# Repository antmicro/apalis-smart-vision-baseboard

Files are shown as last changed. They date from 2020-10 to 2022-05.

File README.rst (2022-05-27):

=============================
Apalis Smart Vision Baseboard
=============================

Copyright (c) 2016-2021 `Antmicro <https://www.antmicro.com>`_





Overview
========

This repository contains open hardware design files for Antmicro’s Apalis Smart Vision Baseboard - a custom baseboard for the Toradex `Apalis family <https://www.toradex.com/computer-on-modules/apalis-arm-family>`_ of SoMs (Systems on Module). The board has a unified FFC connector exposing the MIPI CSI-2 interfaces of the Apalis modules. The FFC connector is electrically compatible with a range of image acquisition platforms developed by Antmicro.

Repository structure
--------------------

The main repository directory contains the Altium PCB project file, the Outjob file, LICENSE and README.
The remaining files are stored in the following directories:

* ``PCB`` -  contains all Altium design files
* ``Libraries`` - contains the component libraries
* ``Documentation`` - contains selected files for device fabrication (schematics in PDF, BoM) generated from the Altium project files
* ``Images`` - contains graphics for this README
* ``3DModel`` - contains files defining the mechanical model of the assembled board

Key features
============

* Toradex Apalis SoM edge connector
* FFC interface exposing up to 2 x 4-lane MIPI CSI-2, depending on the Apalis SoM used
* mSATA connector
* miniPCIe connector
* USB 3.0 host interface
* HDMI output interface
* 2 x Micro USB (debug and OTG)
* Gigabit Ethernet RJ45 connector
* Micro SIM slot
* RTC battery backup
* 9-24V DC power supply voltage

The PCB project files were prepared in Altium Designer 14.1.

Board layout & dimensions
=========================

The picture below presents a general layout of the PCB with marked I/O interfaces.

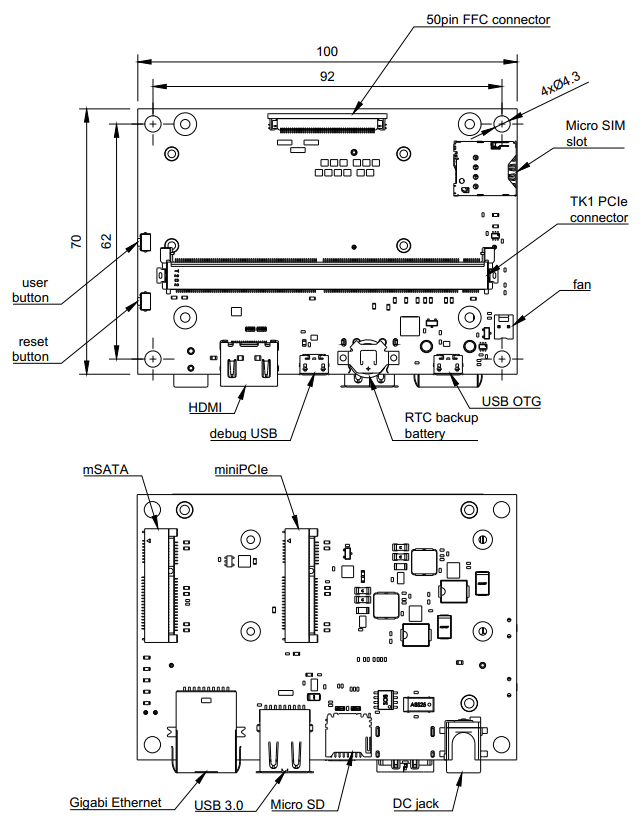
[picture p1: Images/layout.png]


Getting started
===============

The board can be produced and assembled using the provided design files.
Refer to the mechanical layers for more information regarding the PCB stackup recommended for fabrication.
The board accepts power supply voltage in the 6-24VDC range.
It is recommended to use a 12V 2A DC supply to power the board.
The module will start automatically right after applying a power supply.

Debug UART connection
---------------------

Most of the debug messages are provided through the serial console.
The board is equipped with an FTDI chip providing the UART interface to the host PC.
Refer to the schematic sheets for more details.
The default debug UART channel is accessible through ``/dev/ttyUSB0`` (assuming that there are no other FTDI units connected to your PC).
The default baudrate for the serial debug connection is 115200 baud with an 8-bit transmission, 1 stop bit and with no flow control.

License
=======

`Apache-2.0 <LICENSE>`_

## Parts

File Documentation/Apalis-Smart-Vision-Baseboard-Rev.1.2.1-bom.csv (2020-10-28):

Designator | Quantity | Value | Footprint | Manufacturer | MPN
Y1 | 1 | 32.768 kHz | ABS25 | ABRACON | ABS25-32.768KHZ-6-T
J5 | 1 | 114-00841-68 | 114-00841-68 | AMPHENOL COMMERCIAL PRODUCTS | 114-00841-68
IC6, IC7 | 2 | AD8211YRJ | SOT23-5 | ANALOG DEVICES | AD8211YRJ
C13, C14, C36, C56, C59 | 5 | 10n | 0402 | AVX | 04025G103ZAT2A
R24 | 1 | 0R | 0603 | BOURNS | CR0603-J/-000ELF
RST, USR | 2 | TL3340AF160QG | TL3340AF160QG | E-SWITCH | TL3340AF160QG
IC5 | 1 | FT232RQ | QFN-32 | FTDI | FT232RQ-REEL
M1 | 1 | MM70-314-310B1 | Apalis-H | JAE Electronics | MM70-314-310B1
C11, C12 | 2 | 22u | KEMET_C | KEMET | T491C226K025AT
BAT1 | 1 | 3030 | KEYSTONE_CR1025 | Keystone | 3030
D18, D21 | 2 | KPT-1608EC | LED0603 | KINGBRIGHT | KPT-1608EC
D19 | 1 | KPJA-2107CKCK | KPJA-2107 | KINGBRIGHT | KPJA-2107CKCK
D20 | 1 | KPJA-2107SYCK | KPJA-2107 | KINGBRIGHT | KPJA-2107SYCK
D4, D10, D11, D15, D16, D17 | 6 | KPT-1608SGC | LED0603 | KINGBRIGHT | KPT-1608SGC
IC2, IC3 | 2 | LT3976EMSE#PBF | LT3976EMSE | LINEAR TECHNOLOGY | LT3976EMSE#PBF
IC8 | 1 | TC1047AVNBTR | SOT-23 | MICROCHIP | TC1047AVNBTR
IC9 | 1 | MCP79410 | SOIC-8 | MICROCHIP | MCP79410-I/SN
J10, J12 | 2 | Molex 47346-0001 | CON-Molex-047346-0001 | Molex | 473460001
J11 | 1 | MX-22-23-2021 | molex_2223-2021 | Molex | 022232021 A-6373-02A222
J7 | 1 | 47151-1001 | Molex_HDMI_471511001 | MOLEX | 47151-1001
C15, C16 | 2 | 470p | 0402 | MULTICOMP | MC0402B471J500CT
C18, C19, C21, C22, C23, C24, C25, C26, C27, C35, C47, C48, C50 | 13 | 4u7 | 0603 | MULTICOMP | MC0603X475K6R3CT
C3, C4 | 2 | 10p | 0402 | MULTICOMP | MC0402N100D500CT
C32, C51 | 2 | 1u | 0402 | MULTICOMP | MC0402F105Z6R3CT
R11, R13, R26, R27, R31, R32, R41, R44, R45 | 9 | 330R | 0402 | MULTICOMP | MCMR04X3300FTL
R5 | 1 | 576k | 0402 | MULTICOMP | MCMR04X5763FTL
R6 | 1 | 130k | 0402 | MULTICOMP | MCMR04X1303FTL
R8 | 1 | 54k9 | 0402 | MULTICOMP | MCMR04X5492FTL
R9, R10, R16, R17, R18, R20, R21, R22, R28, R38, R39, R40, R46 | 13 | 10k | 0402 | MULTICOMP | MCMR04X1002FTL
C1 | 1 | 4u7 | 0402 | MURATA | GRM155R60G475ME
C7, C8, C9, C10 | 4 | 47u | 1206 | MURATA | GRM31CC80J476KE18L
L1 | 1 | LQH3NPN2R2NM0L | LQH3NPN2R2NM | MURATA | LQH3NPN2R2NM0L
L4, L5, L6, L9 | 4 | BLM18SG121TN1D | 0603 | MURATA | BLM18SG121TN1D
IC4 | 1 | IP4791CZ12 | IP4791CZ12 | NXP | IP4791CZ12
Q1, Q3 | 2 | PMGD780SN | SOT-363 | NXP | PMGD780SN,115
D1, D2 | 2 | MBRS540T3G | SMC-403-03 | ON SEMICONDUCTOR | MBRS540T3G
D3 | 1 | BAV70LT3G | SOT-23 | ON SEMICONDUCTOR | BAV70LT3G
IC11 | 1 | NCP380HSNAJAAT1G | TSOP-6 | ON Semiconductor | NCP380HSNAJAAT1G
R25 | 1 | 0R | 0402 | Panasonic | ERJ2GE0R00X
R29, R30 | 2 | 0R05 | 1206 | PANASONIC | ERJL08KF50MV
R33, R34, R42, R43 | 4 | 4k7 | 0402 | Panasonic | ERJ2GEJ472X
R53 | 1 | 13k | 0402 | Panasonic | ERJ2GEJ133X
IC12, IC13, IC14, IC15, IC16, IC17, IC18, IC19, IC20, IC21, IC22, IC23 | 12 | EClamp8052P | SGP1917N5 | SEMTECH | ECLAMP8052P.TCT
C17, C33, C34, C37, C41, C49, C52, C60 | 8 | 100n | 0402 | TDK | C1005X5R0J104K050BA
C20 | 1 | 10u | 0402 | TDK | C1005X5R0J106M050BC
C5, C6 | 2 | 470n | 0402 | TDK | MC0402X474K6R3CT
J2, J4 | 2 | 1759503-1 | 1759503-1 | TE CONNECTIVITY | 1759503-1
D5, D7, D9, D22 | 4 | TPD4E05U06 | TPD4E05U06_PASS | Texas Instruments | TPD4E05U06DQAR
D6, D12, D13, D14 | 4 | TPD6E05U06 | TPD6E05U06_PASS | Texas Instruments | TPD6E05U06RVZR
D8, D23 | 2 | TPD2E2U06DRLR | TPD2E2U06DRLR | Texas Instruments | TPD2E2U06DRLR
IC1 | 1 | LM3671MF-1.5 | SOT23-5N | TEXAS INSTRUMENTS | LM3671MF-1.5/NOPB
IC10 | 1 | ADS1015IDGST | MSOP10 | TEXAS INSTRUMENTS | ADS1015IDGST
C42 | 1 | 100u | KEMET_A | VISHAY | 298D107X06R3A2T
L2, L3 | 2 | IHLP2525CZER2R2M01 | IHLP-2525CZ-01 | VISHAY | IHLP2525CZER3R3M01
Q2 | 1 | SI2323DS | SOT-23 | Vishay | SI2323DS-T1-E3
R1, R2 | 2 | 1M | 0402 | VISHAY | CRCW04021M00FKED
R14, R15 | 2 | 22R | 0402 | VISHAY | CRCW040222R0FKED
R37 | 1 | 470R | 0402 | VISHAY | CRCW0402470RFKED.
R7 | 1 | 316k | 0402 | VISHAY | CRCW0402316KFKED
C2, C28, C29, C30, C31, C38, C39, C40, C43, C44, C45, C46, C55, C57, C58 | 15 | 10u | 0603 | Walsin | 0603X106M6R3CT
C53, C54 | 2 | 6p | 0402 | WALSIN | 0402N6R0D500CT
J1 | 1 | 694106106102 | 694106106102 | WURTH ELEKTRONIK | 694106106102
J3 | 1 | 693021010811 | 693021010811 | WURTH ELEKTRONIK | 693021010811
J6 | 1 | 68715014522 | 68715014522 | WURTH ELEKTRONIK | 68715014522
J8 | 1 | 692122030100 | 692122030100 | WURTH ELEKTRONIK | 692122030100
J9 | 1 | 7498111001A | 7498111001A | WURTH ELEKTRONIK | 7498111001A
SP1, SP2 | 2 | 9774030360 | M3-3mm | WURTH ELEKTRONIK | 9774030360
SP3, SP4, SP5, SP6 | 4 | 9774050151 | M2.5-5mm | WURTH ELEKTRONIK | 9774050151
SP7, SP8 | 2 | 9774080360 | M3-8mm | WURTH ELEKTRONIK | 9774080360
R3, R4 | 2 | 2R | 0402 | YAGEO | MC00625W040212R0

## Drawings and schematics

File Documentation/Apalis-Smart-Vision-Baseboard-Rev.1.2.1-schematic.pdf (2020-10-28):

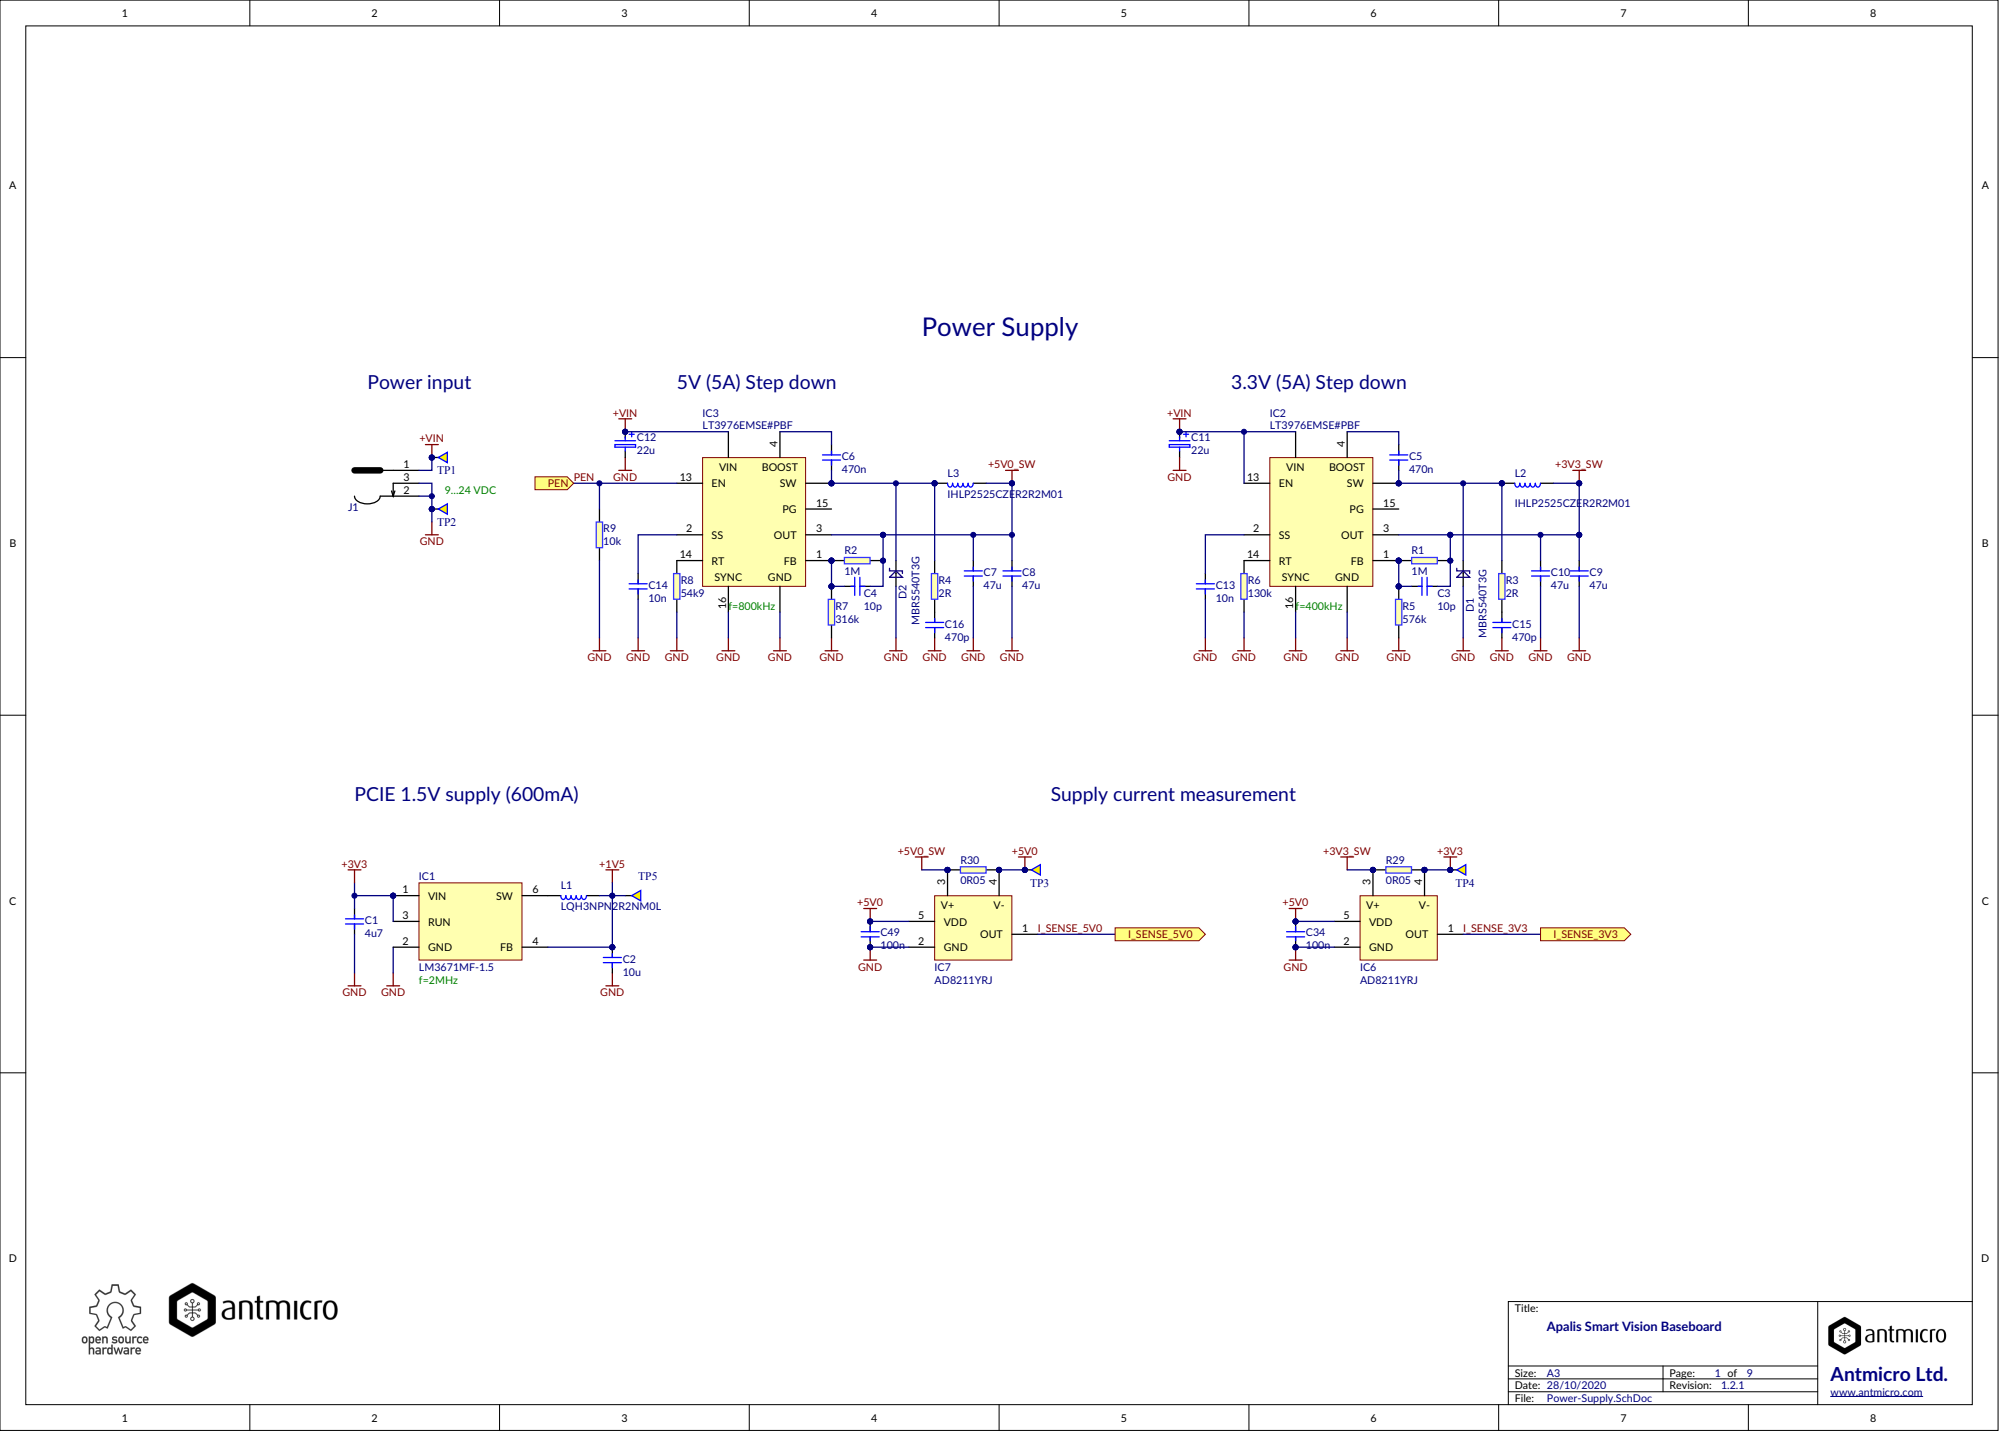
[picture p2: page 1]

Title: Apalis Smart Vision Baseboard

Size: A3 | Page: 1 of 9 | Antmicro Ltd. www.antmicro.com
Date: 28/10/2020 | Revision: 1.2.1

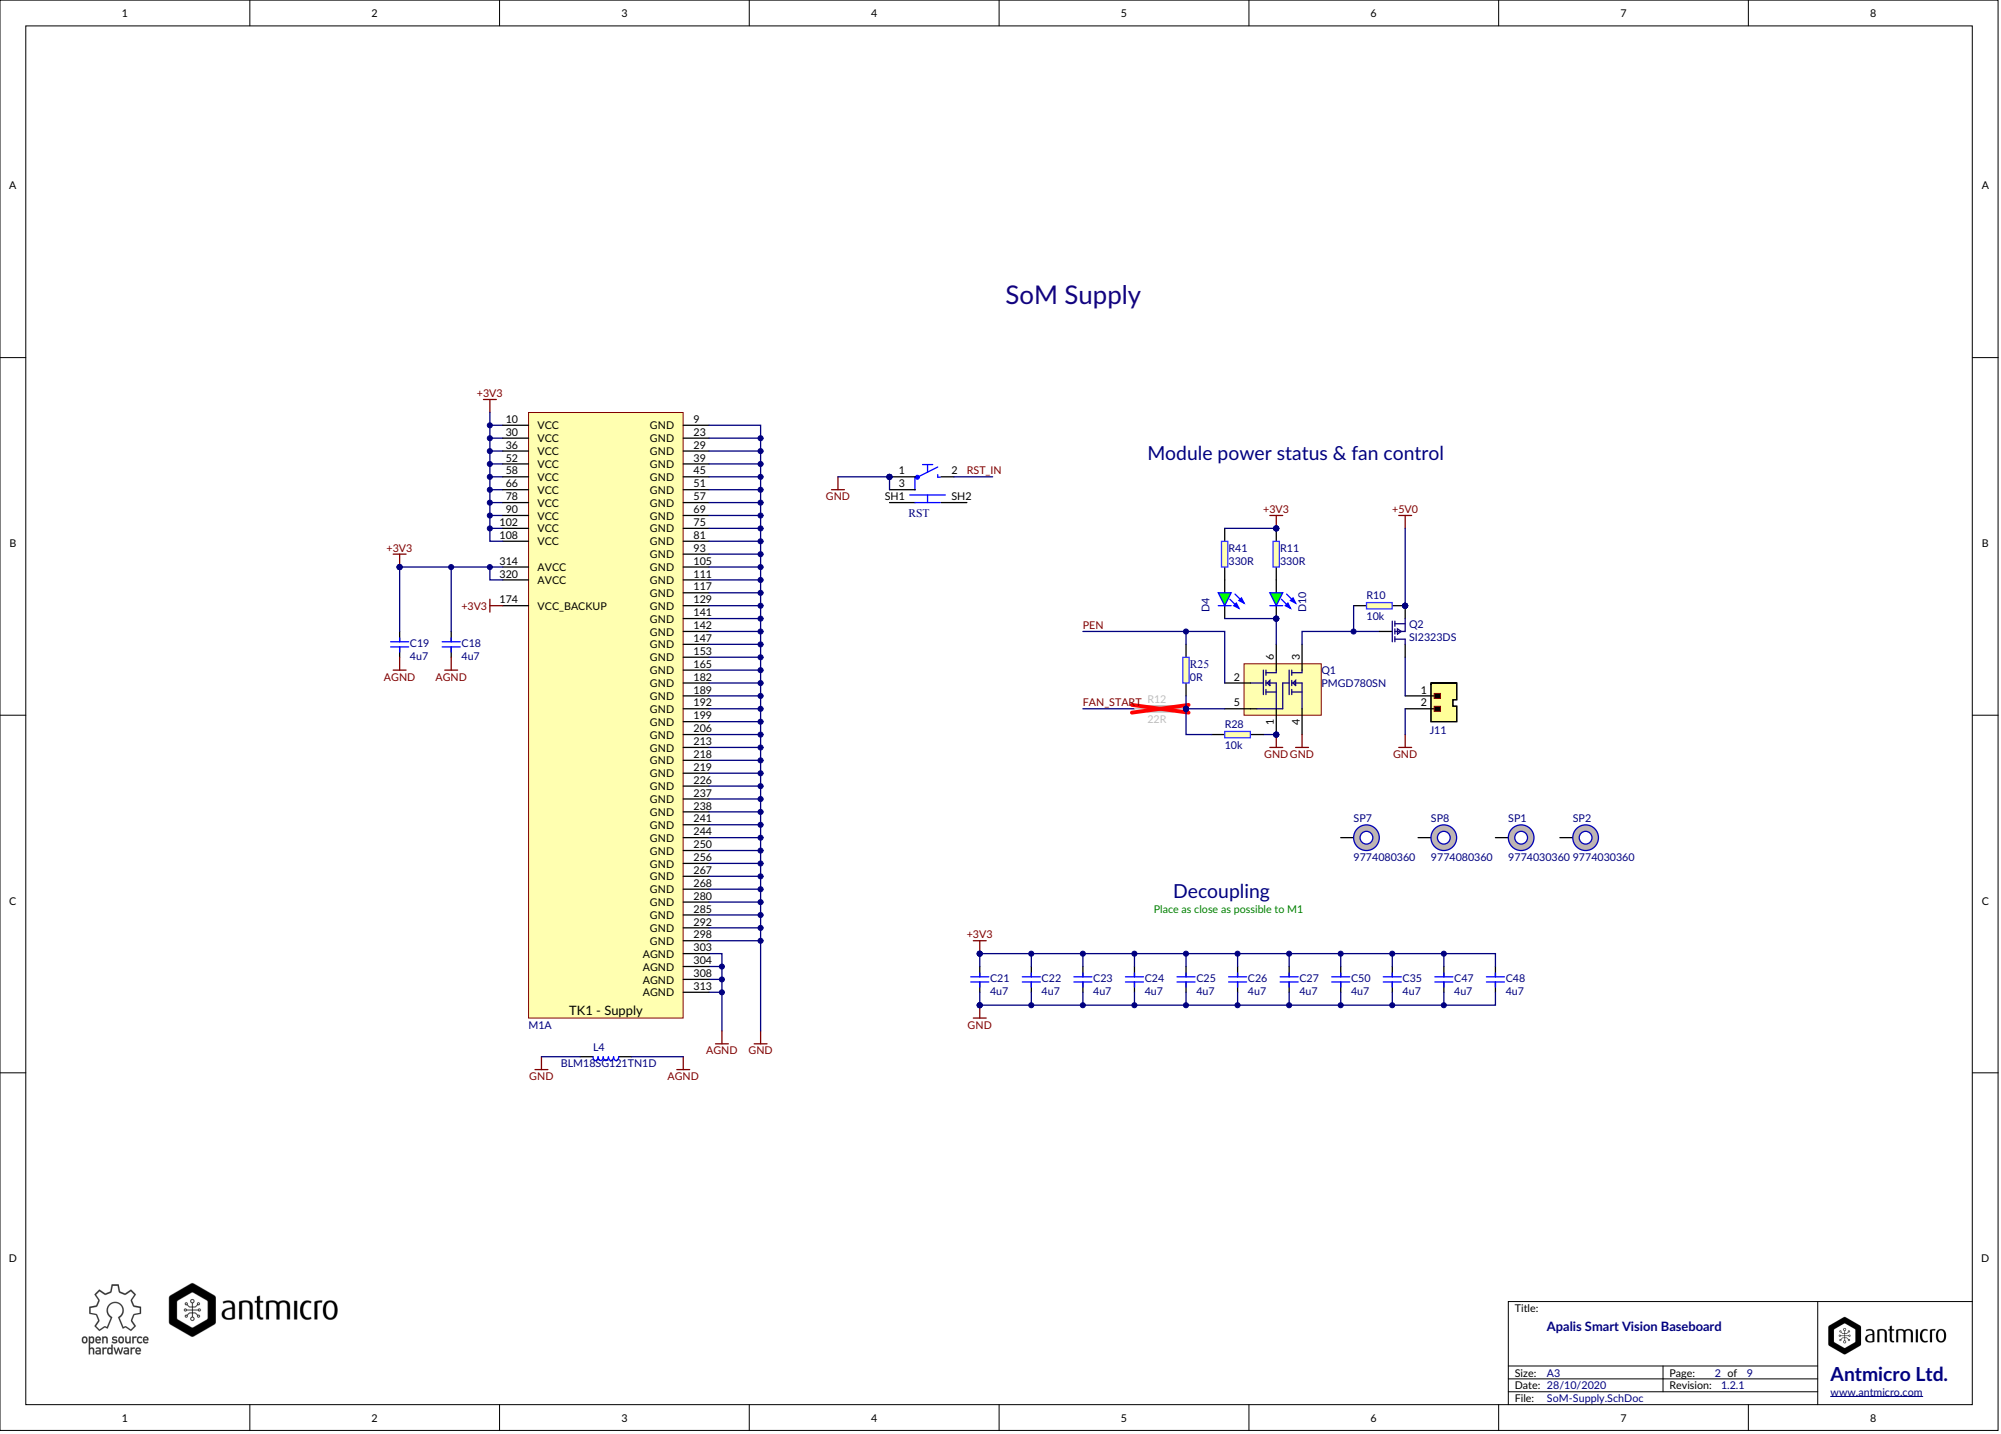
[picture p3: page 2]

VCC 30
VCC 36
VCC 52
VCC 58

Module power status & fan control

VCC 78

VCC 102

Place as close as possible to M1

Title:

A3 | Page: 2 of 9

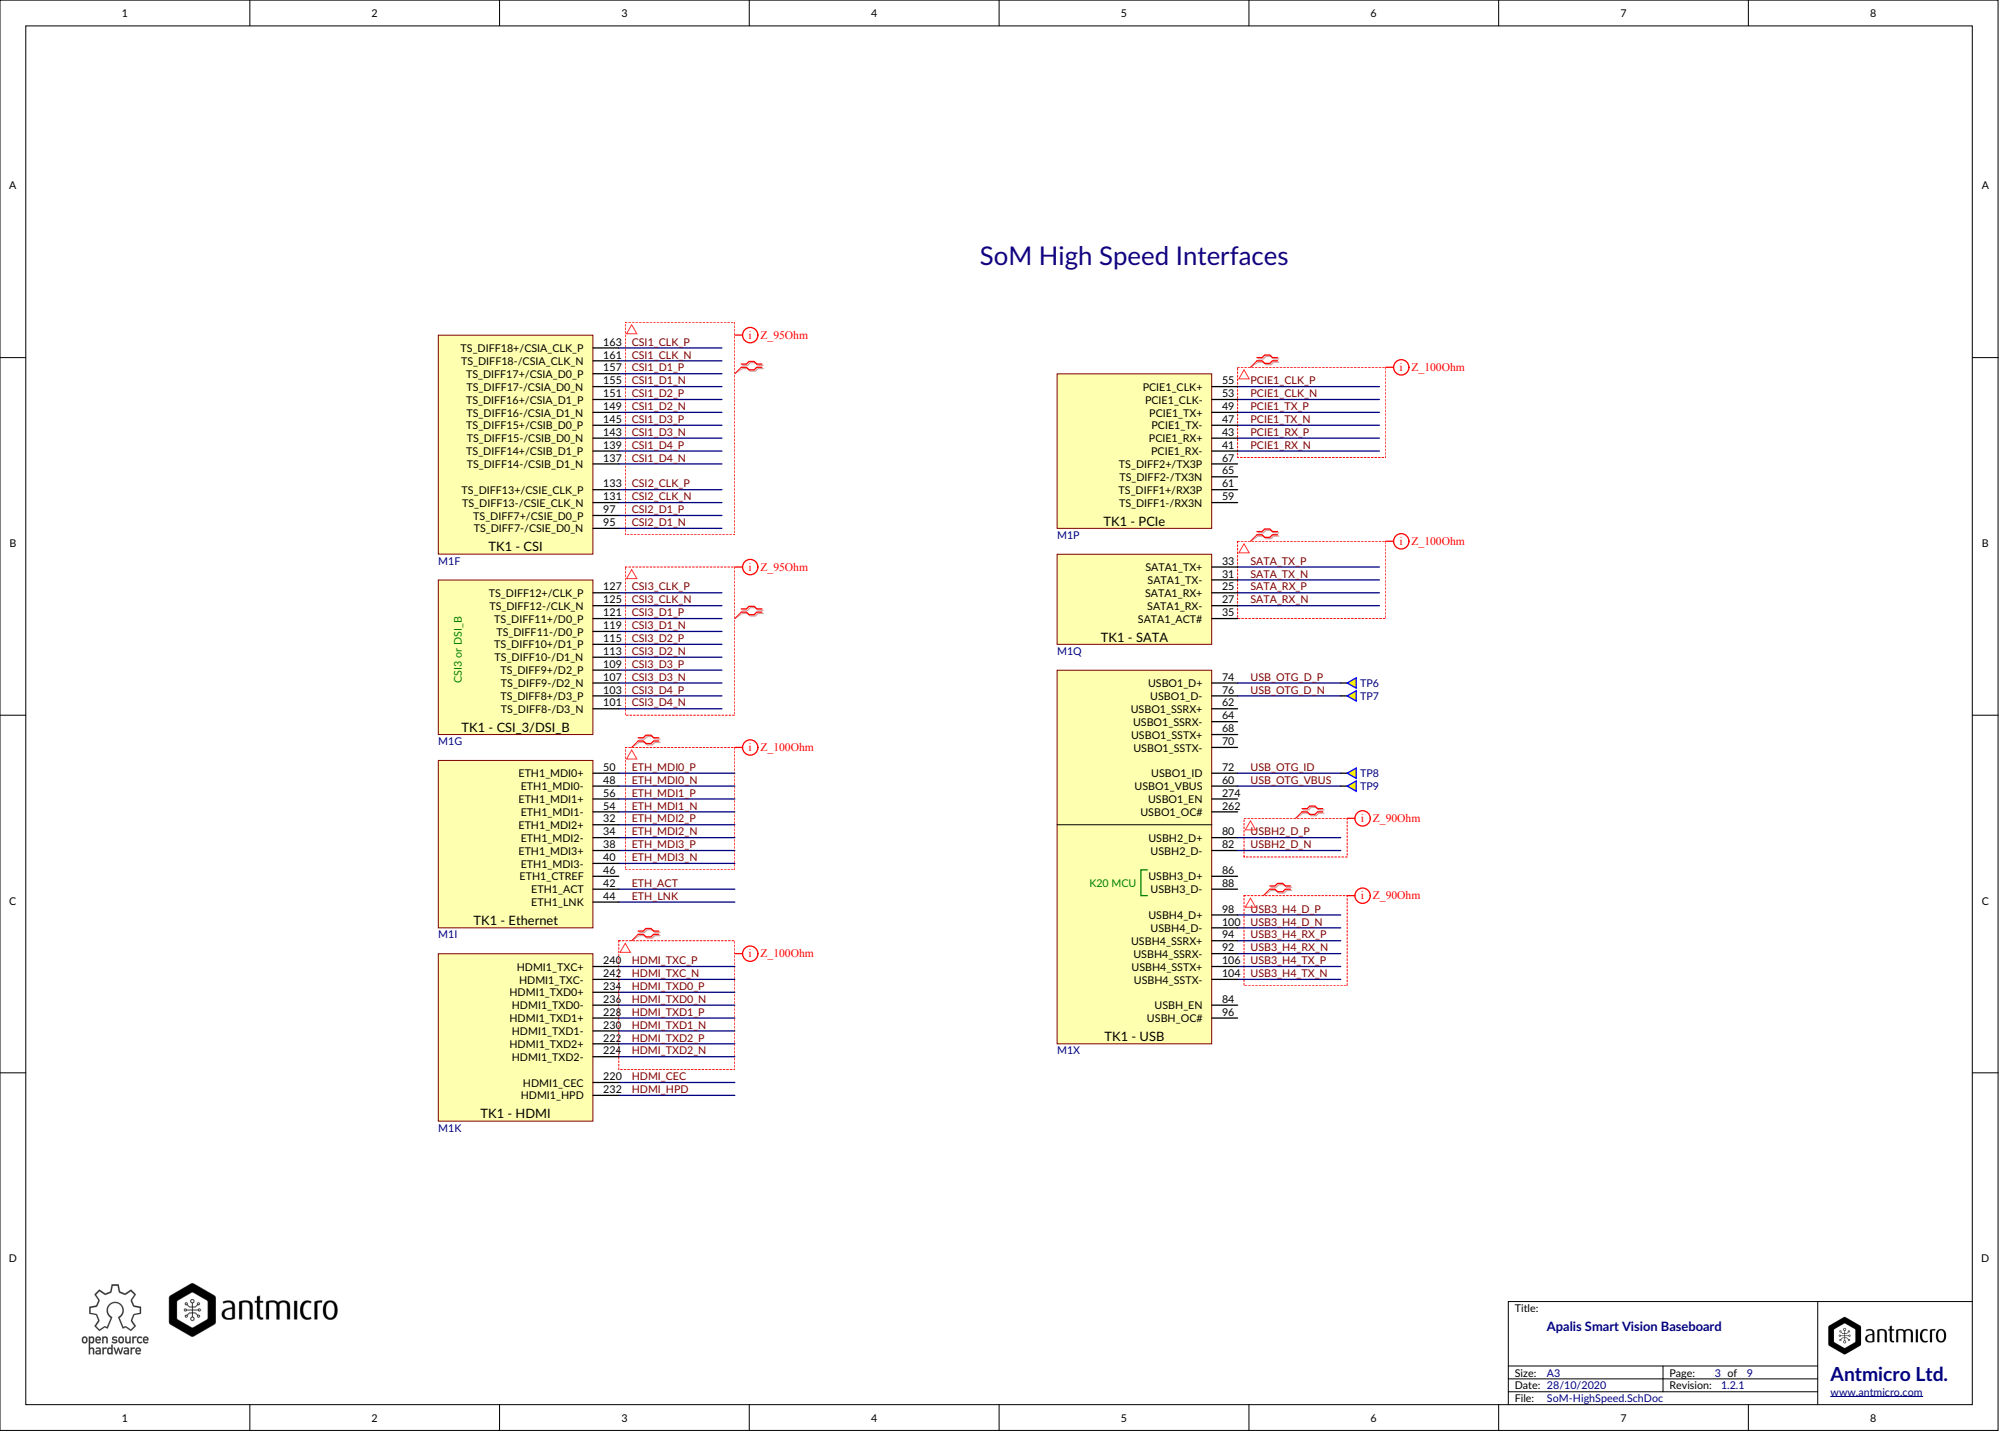
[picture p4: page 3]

SoM High Speed Interfaces

Title:

A3 | Page: 3 of

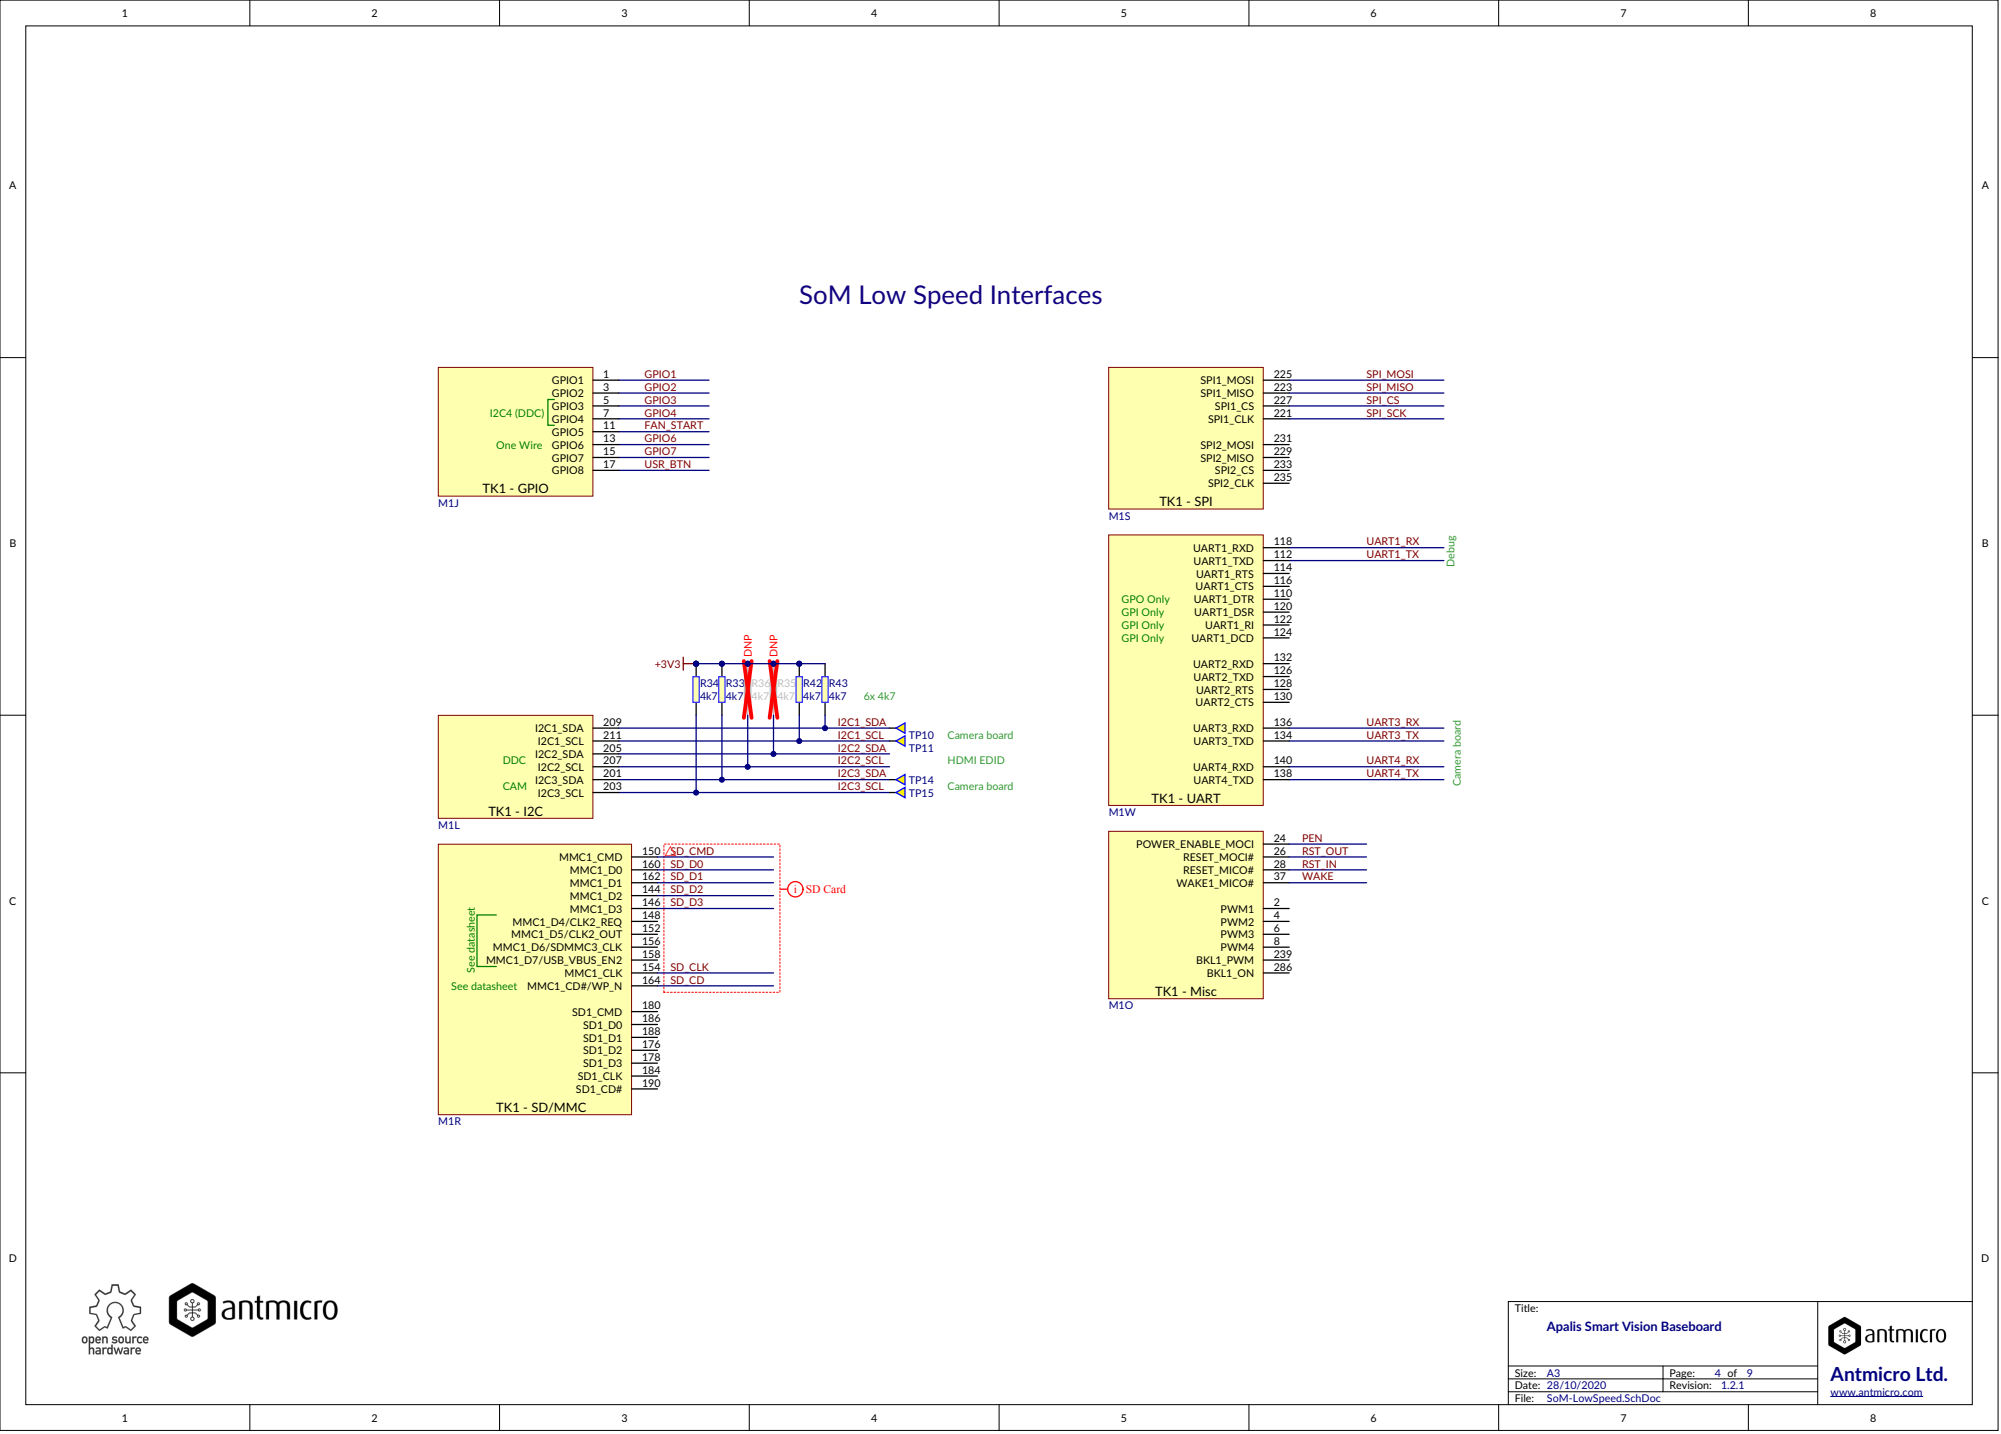
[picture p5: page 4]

SoM Low Speed Interfaces

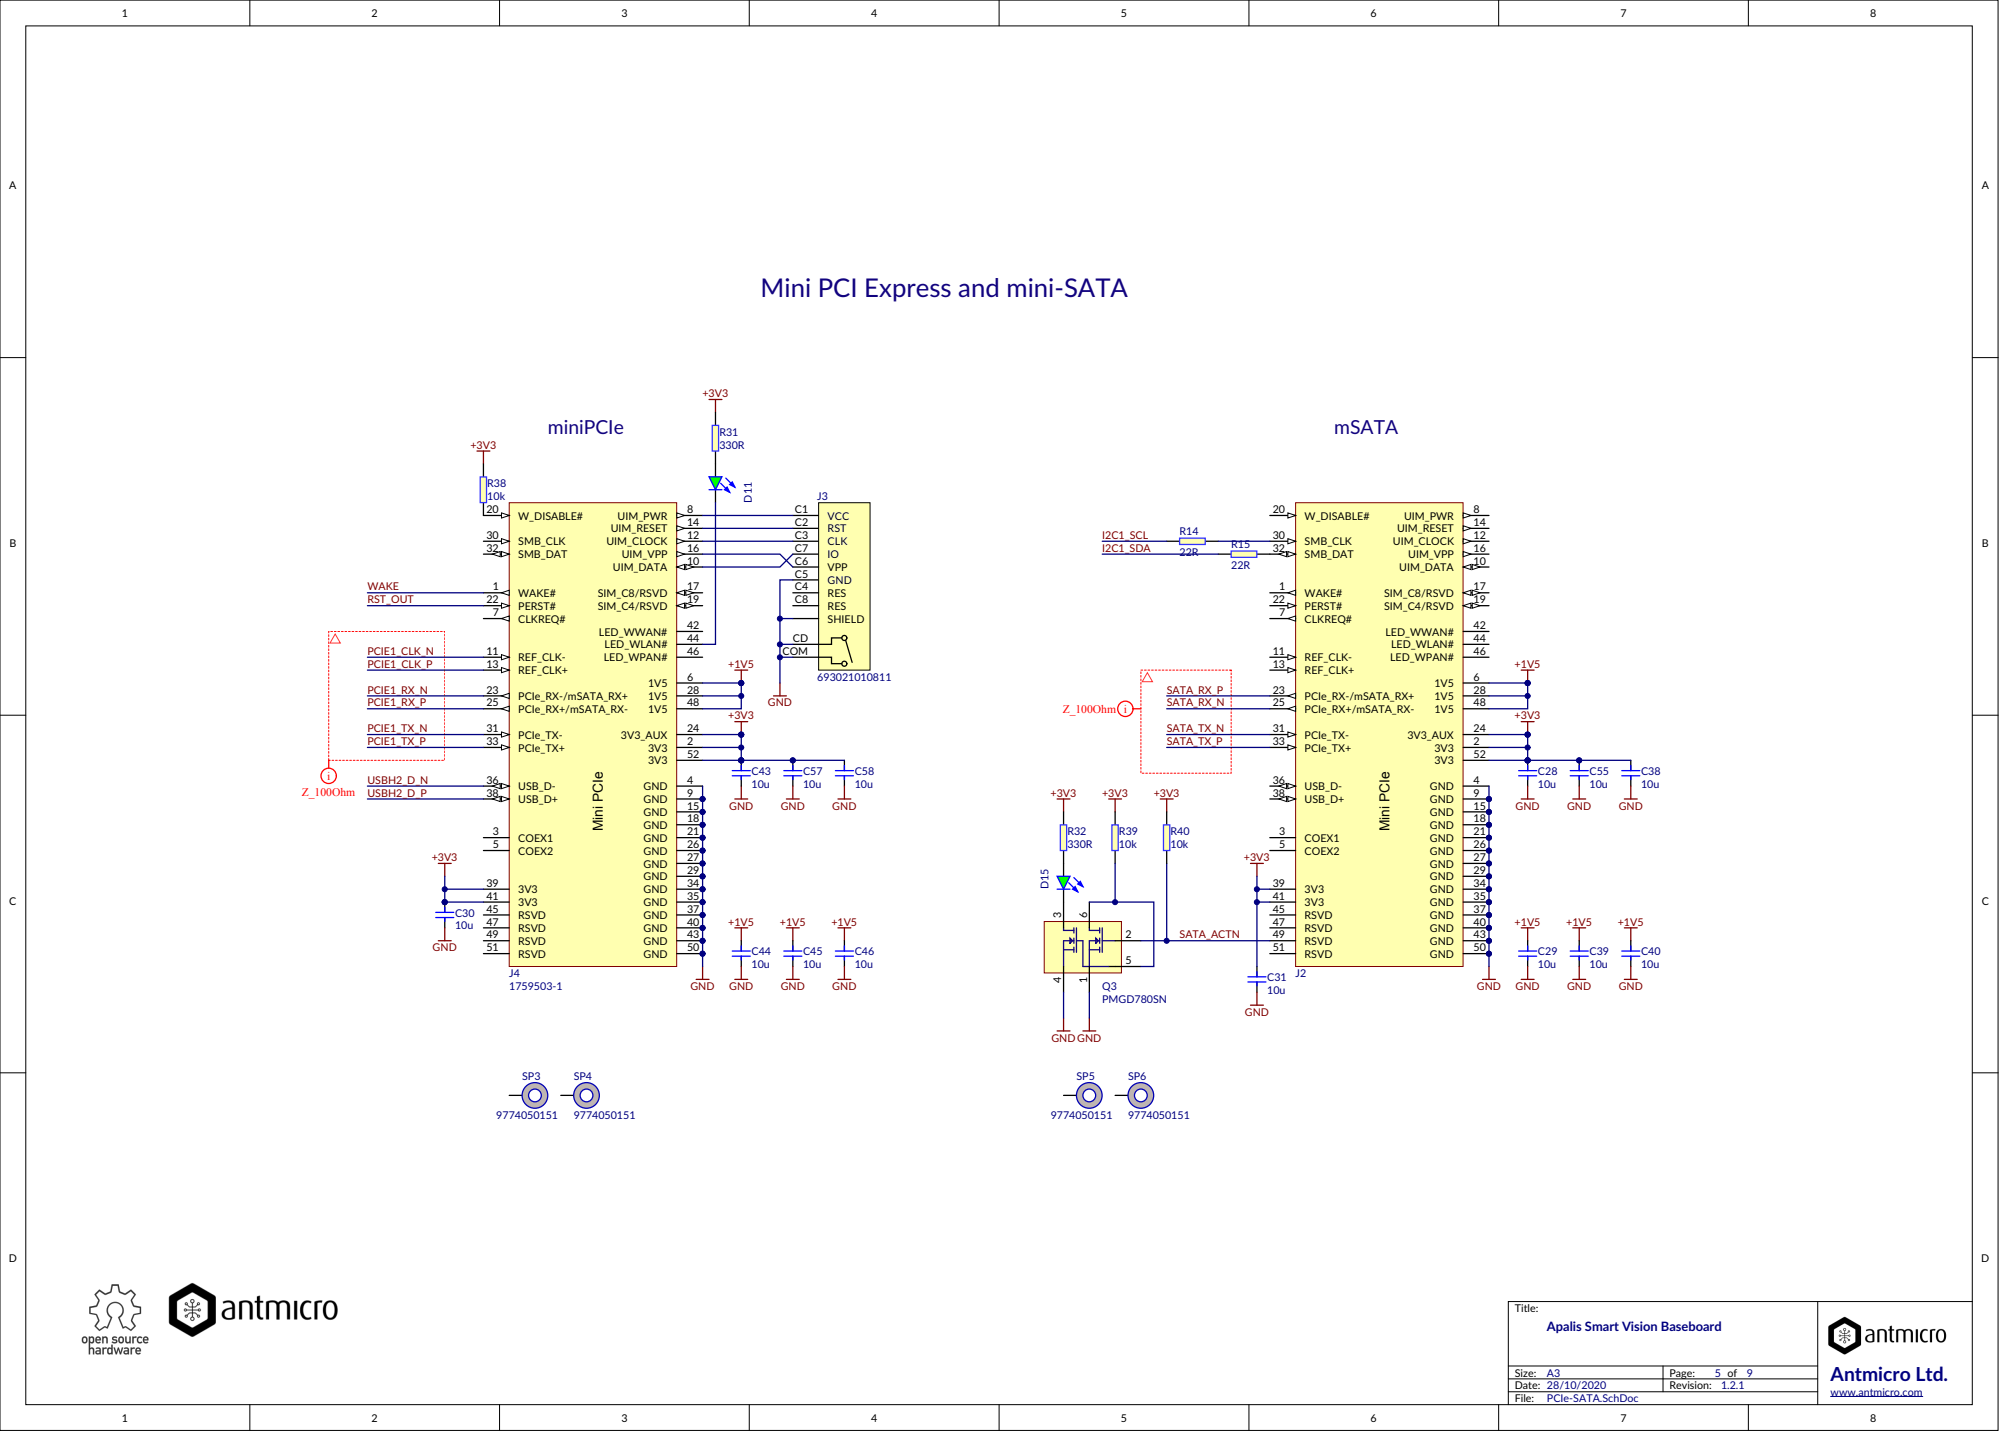
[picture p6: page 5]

Mini PCI Express and mini-SATA

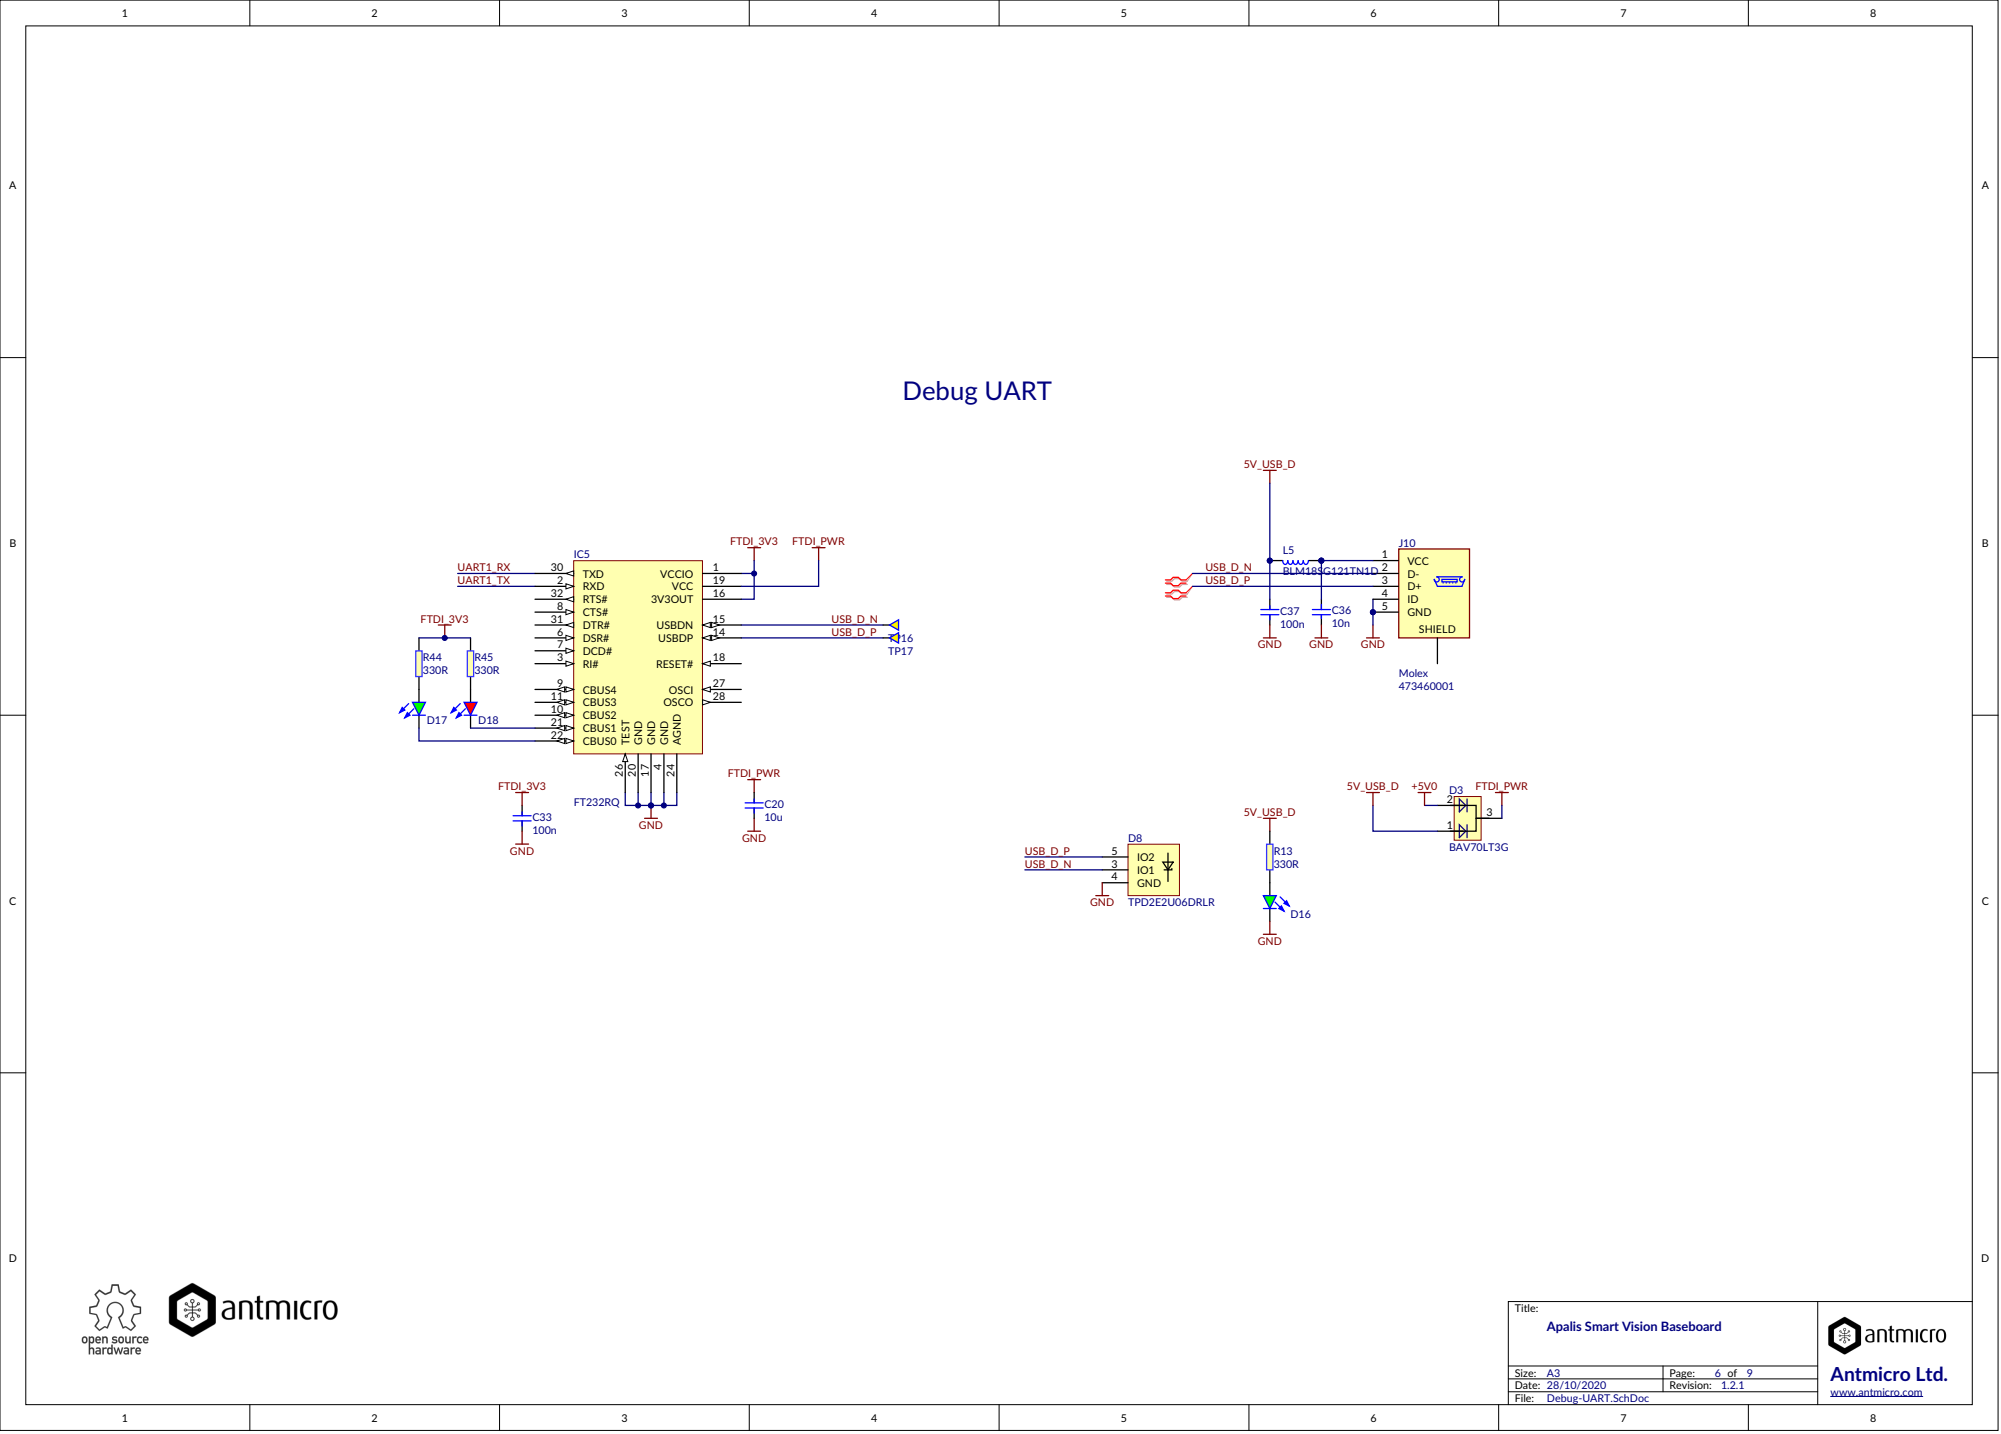
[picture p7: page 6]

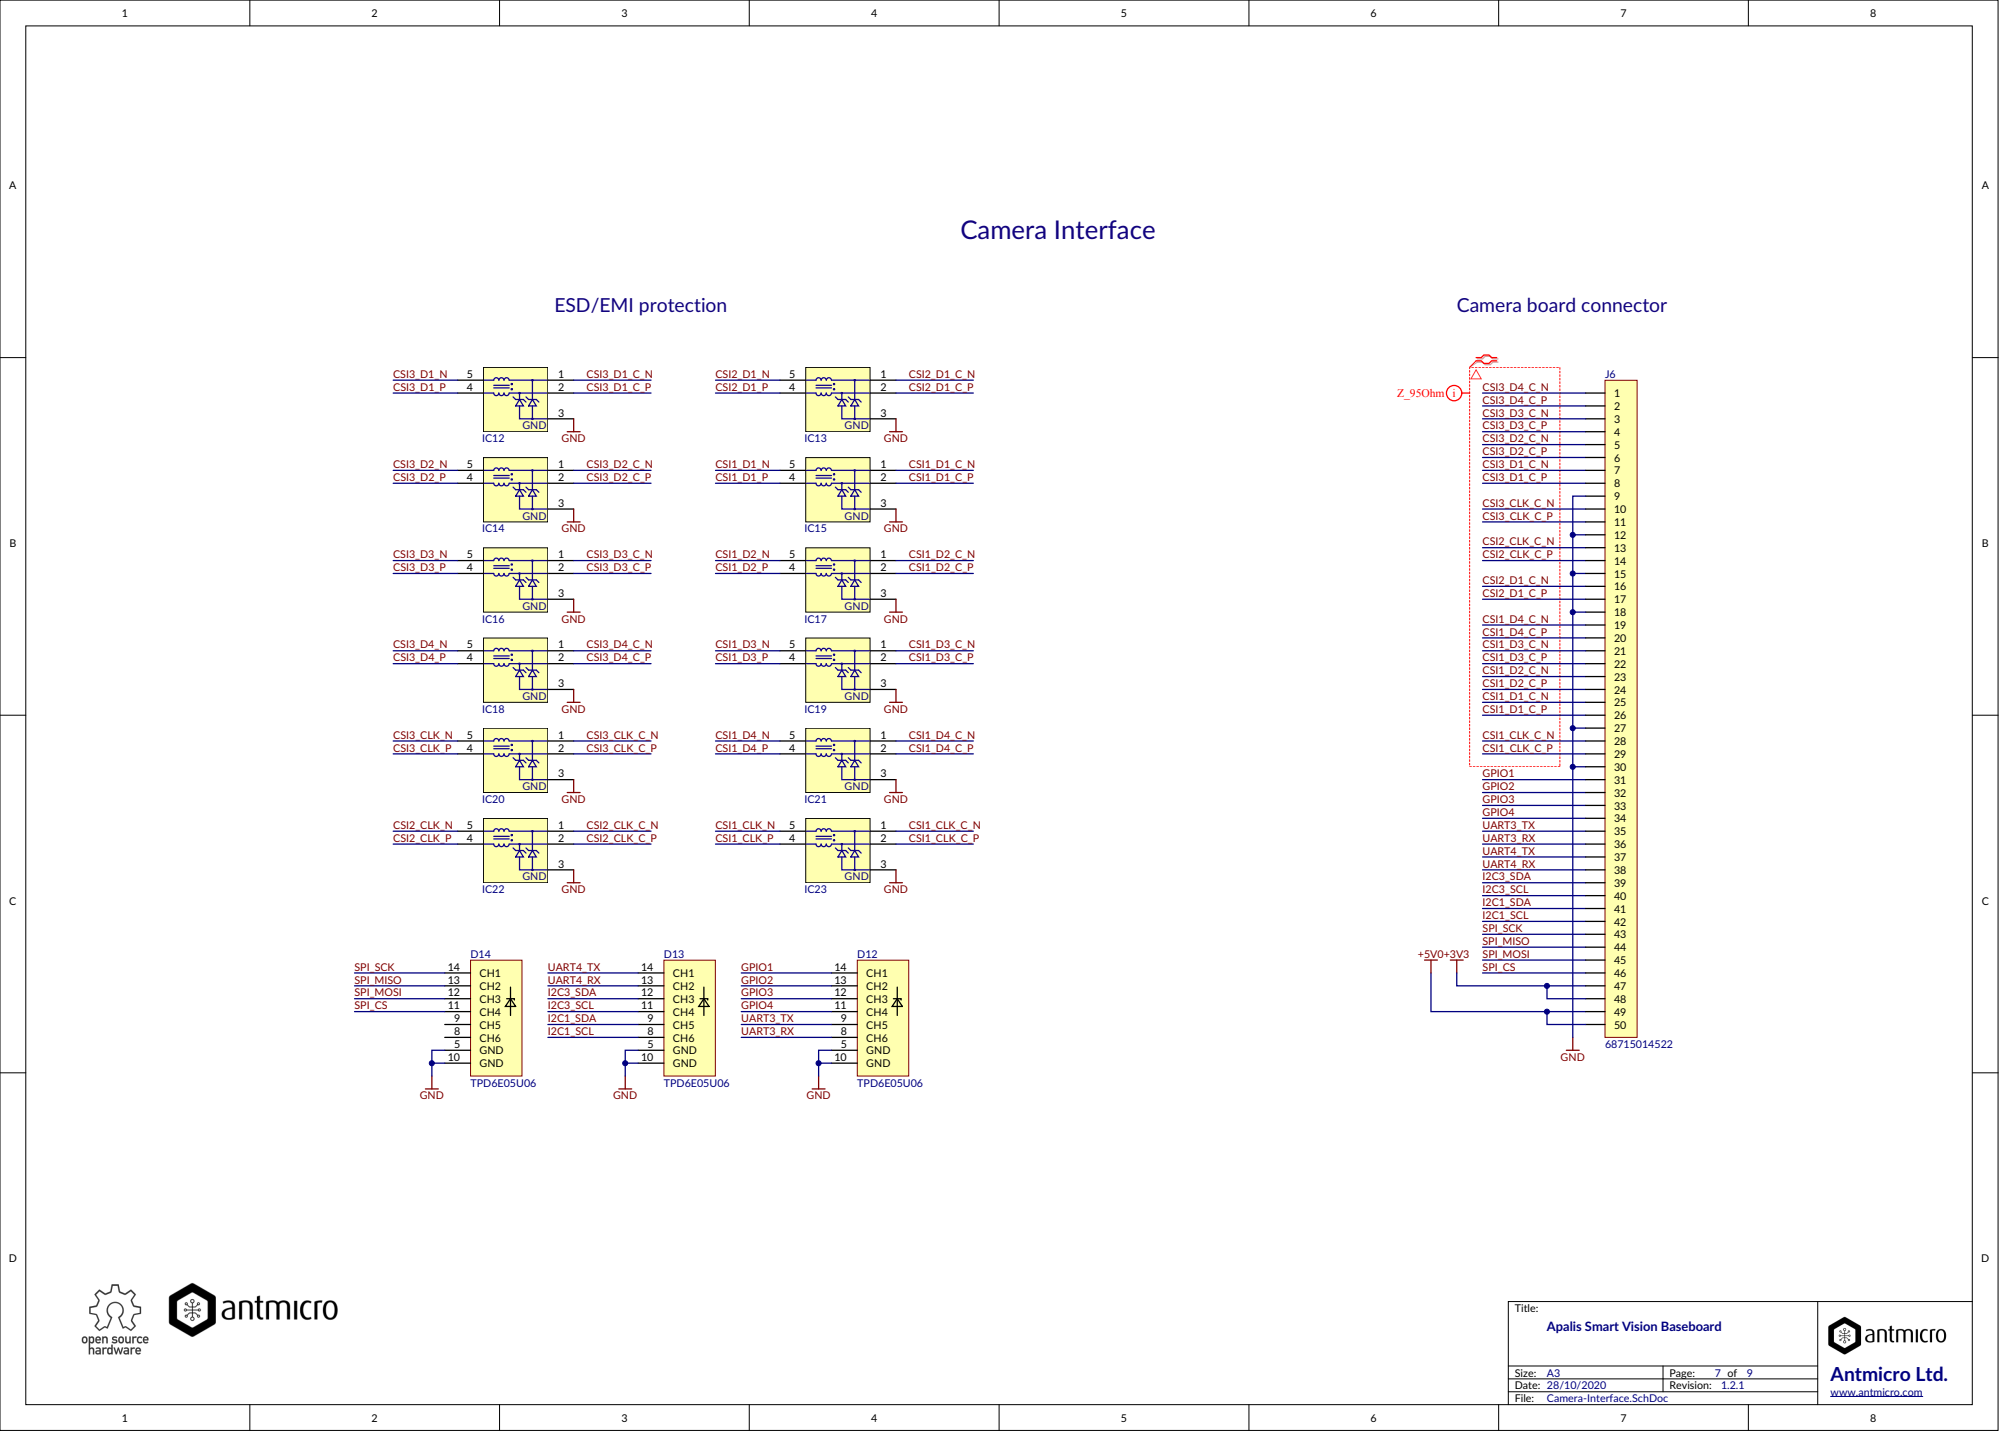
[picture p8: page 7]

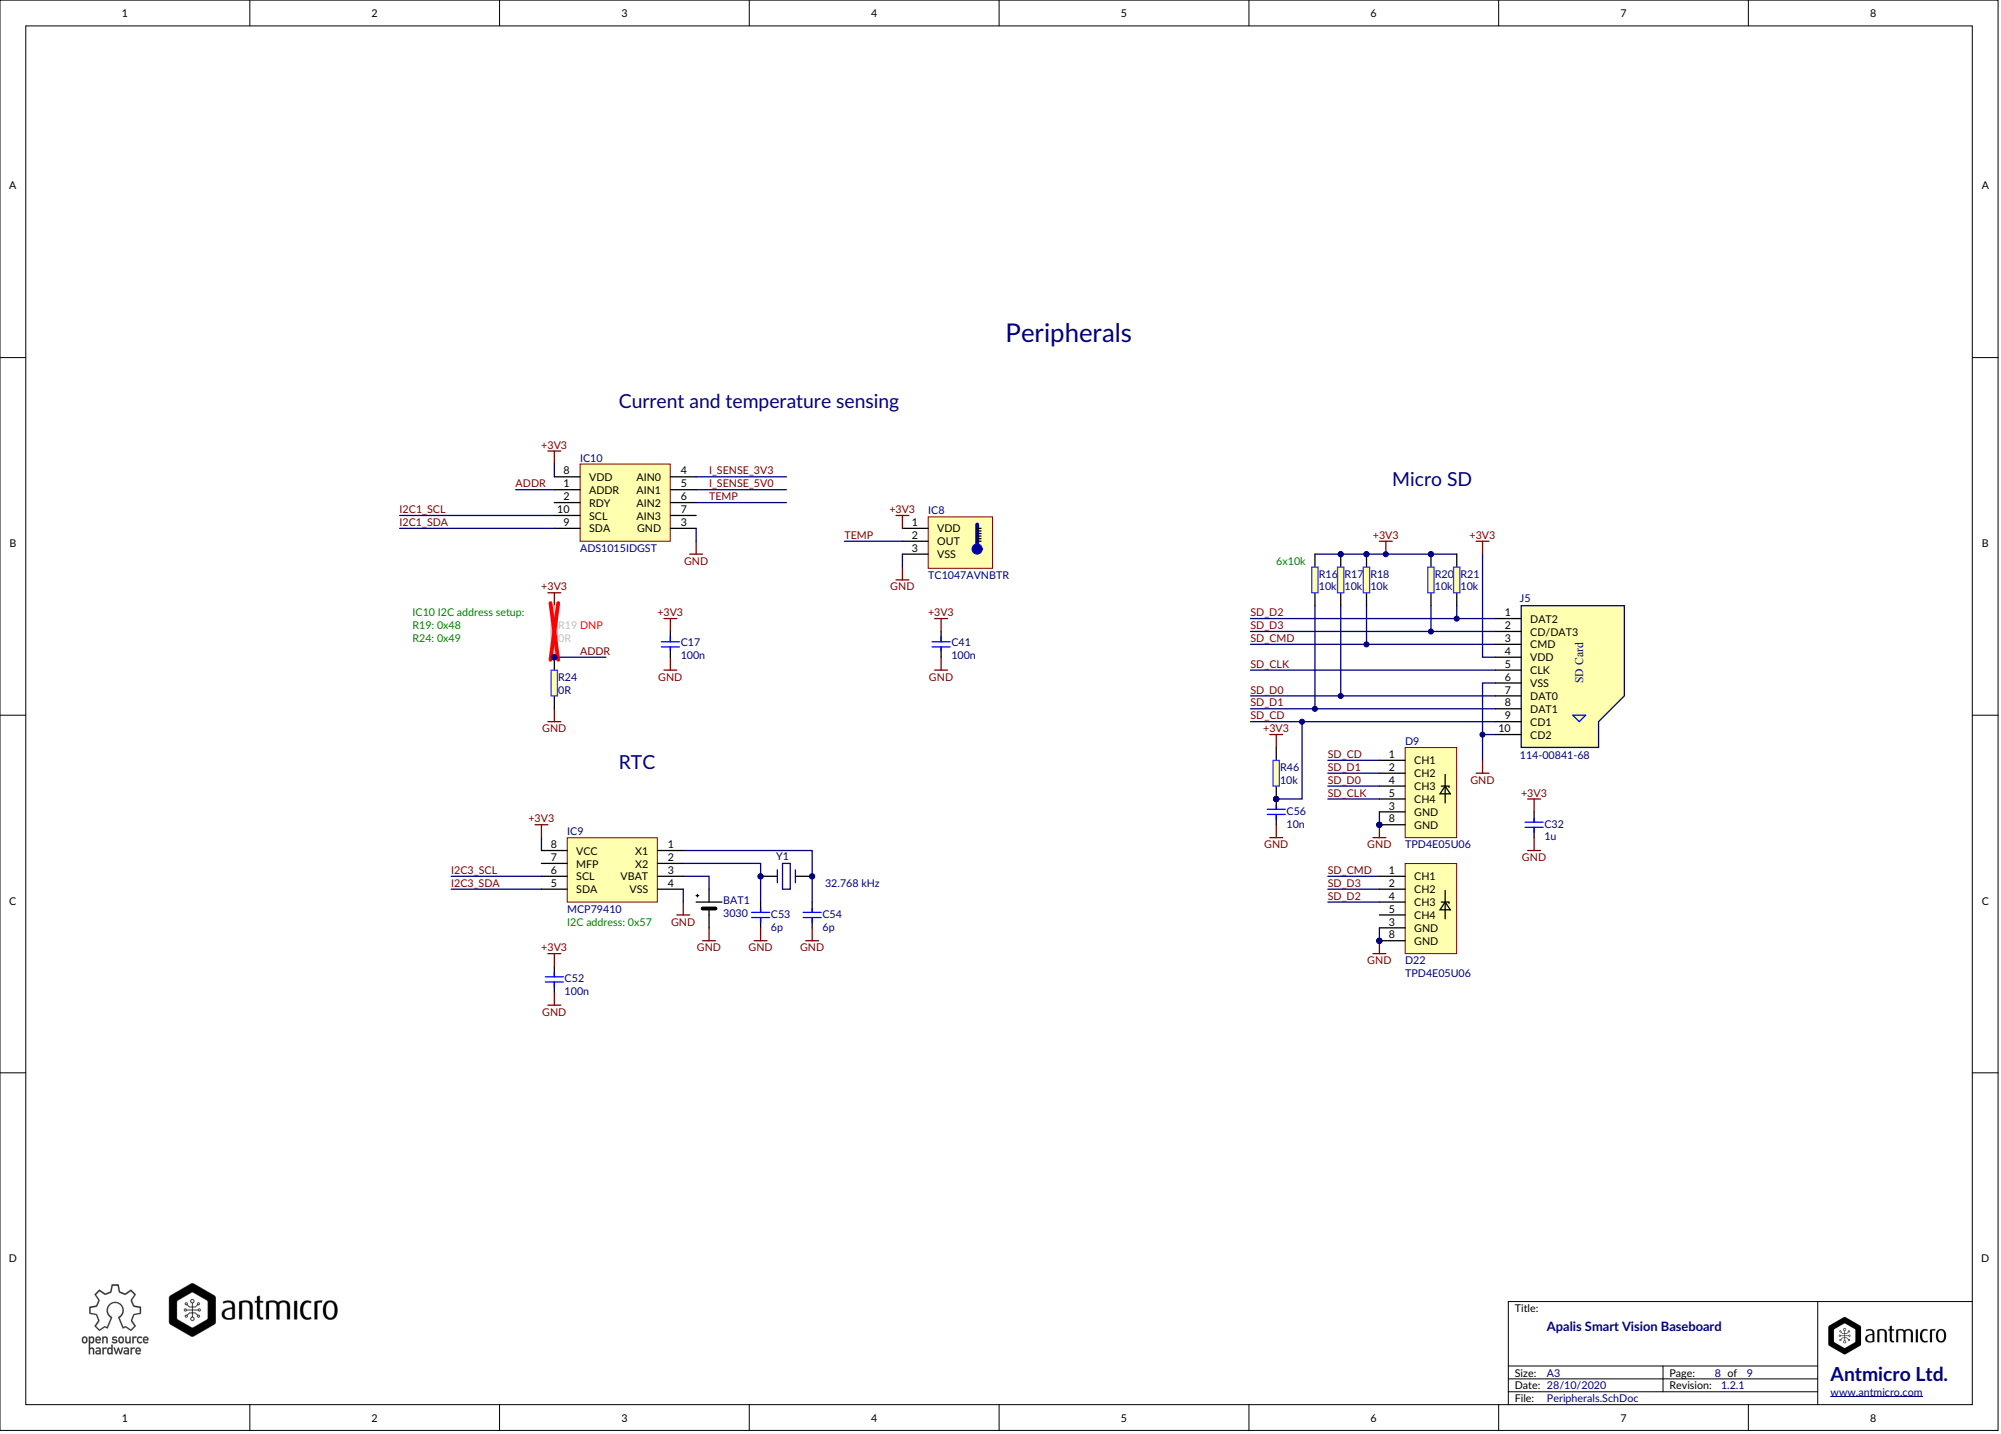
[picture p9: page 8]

Current and temperature sensing

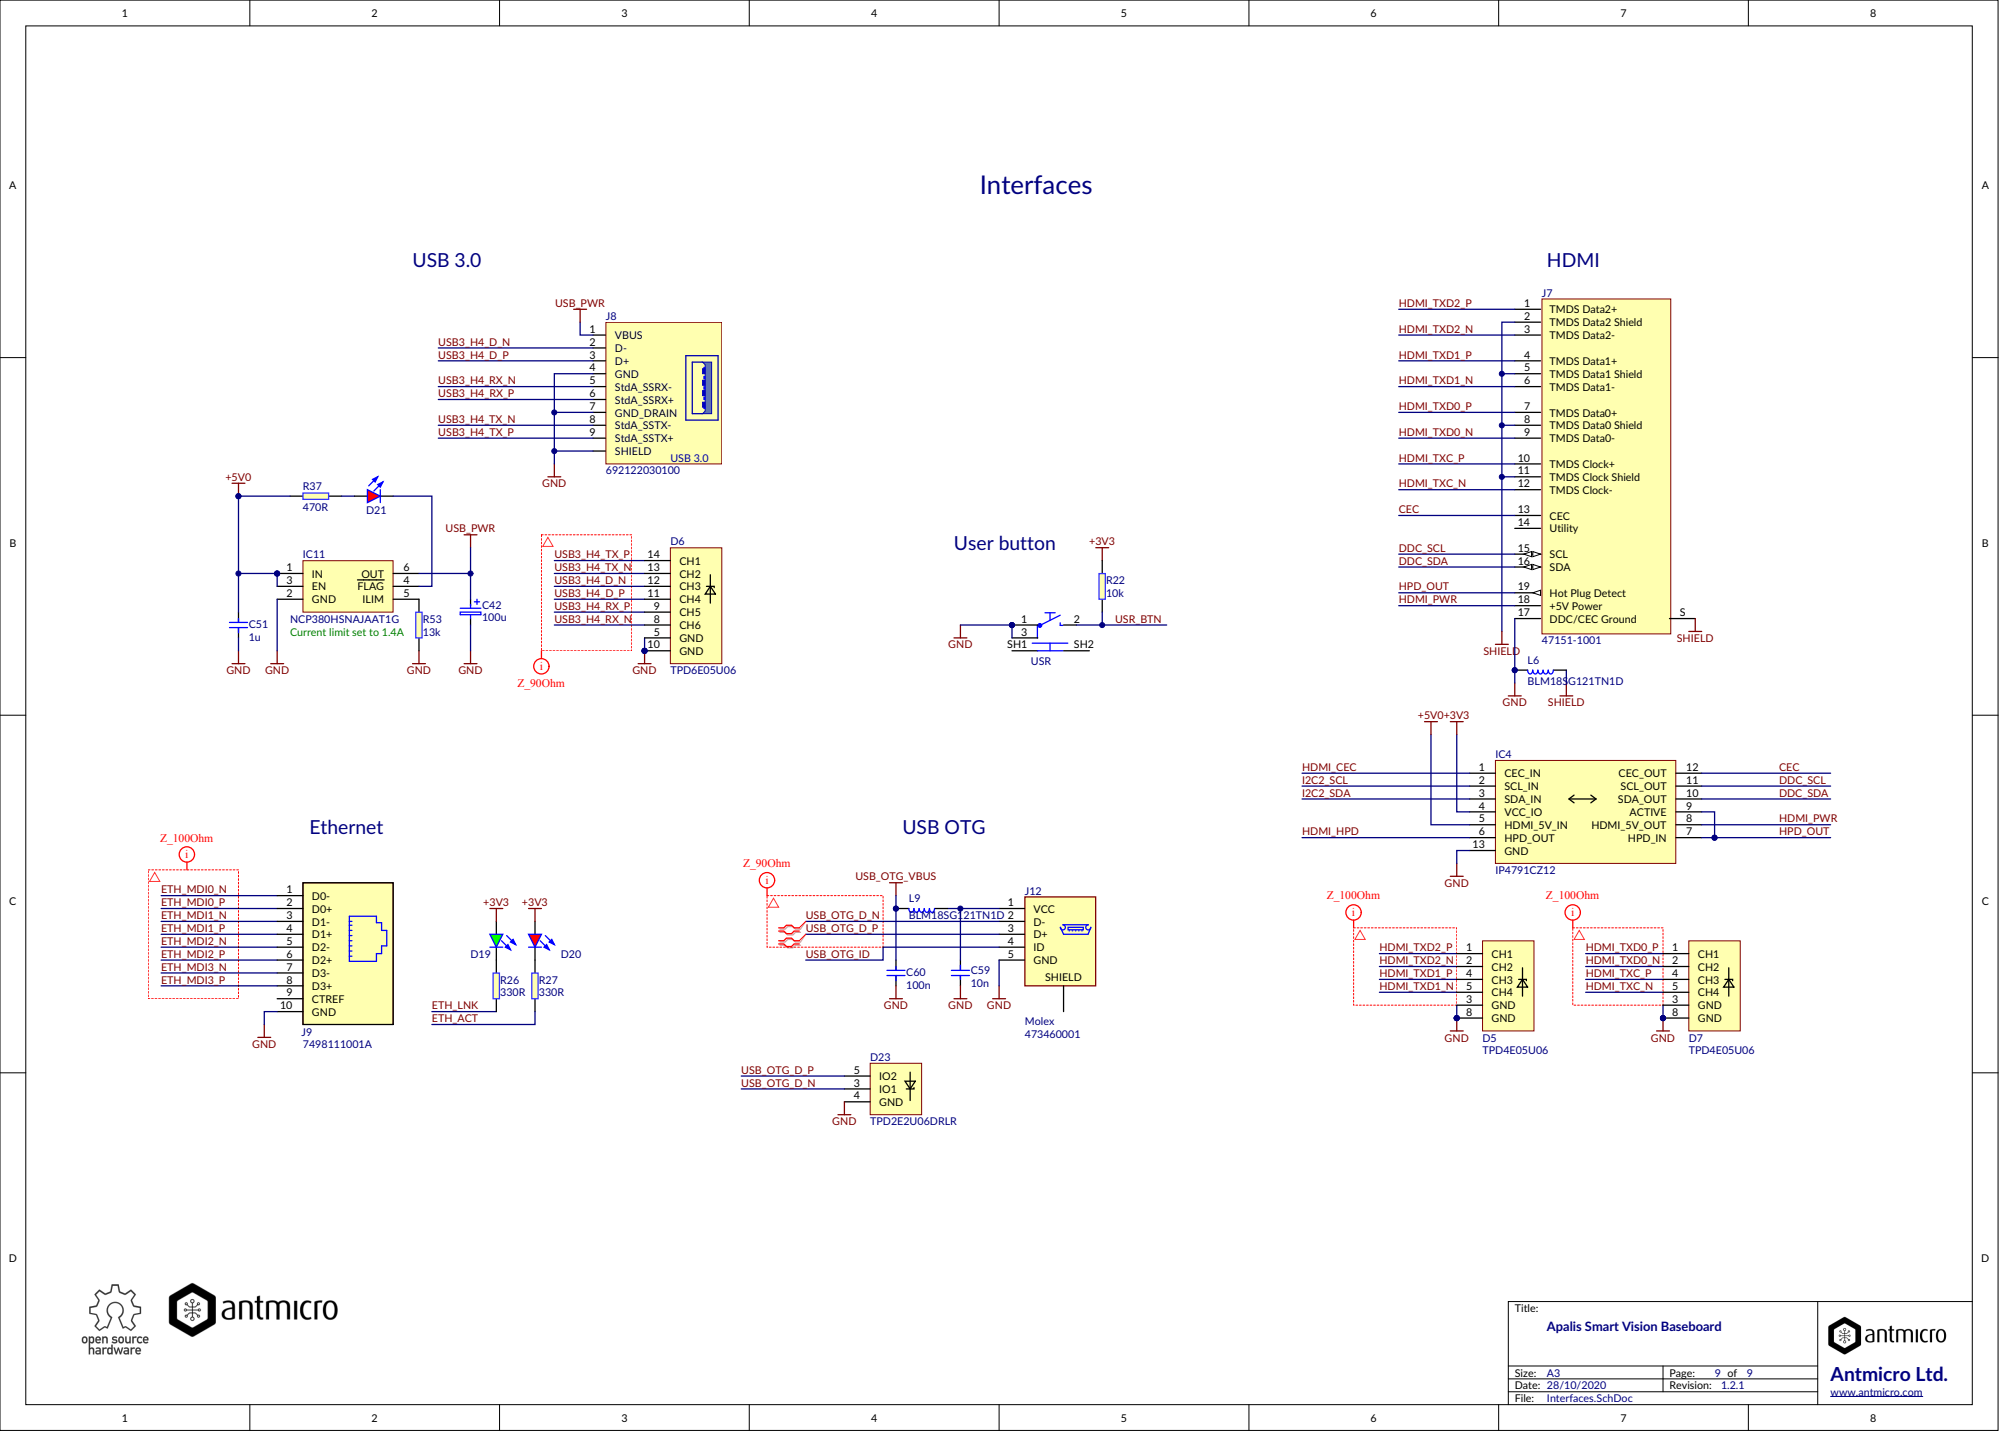
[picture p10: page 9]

TMDS Data0- 9 TMDS Clock+ 10 TMDS Clock Shield 11

TMDS Clock- 12 CEC 13 Utility 14

NCP380HSNAJAAT1G
Current limit set to 1.4A

Title:

A3 | Page: 9 of 9

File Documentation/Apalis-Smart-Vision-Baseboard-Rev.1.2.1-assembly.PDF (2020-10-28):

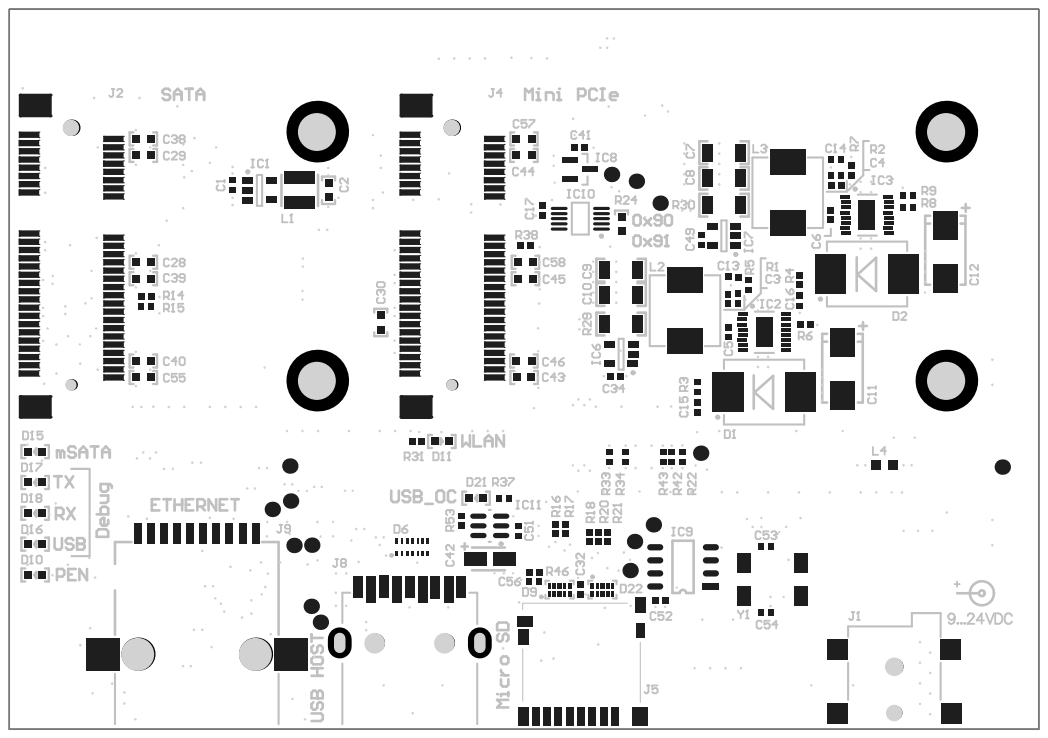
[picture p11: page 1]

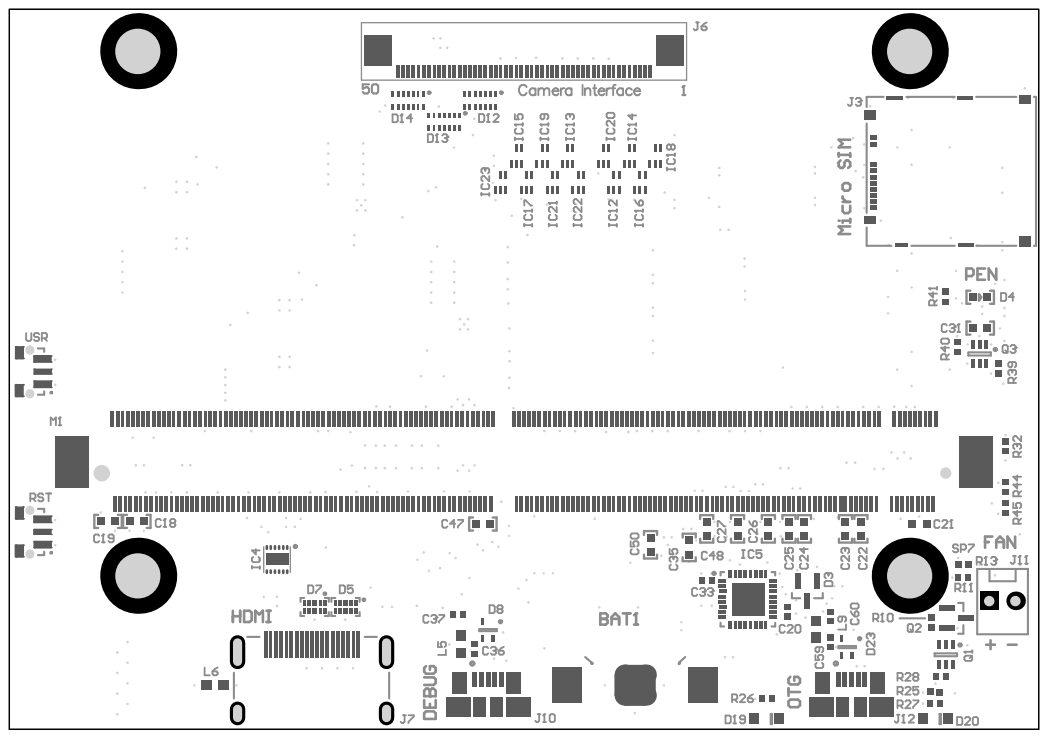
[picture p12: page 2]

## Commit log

2020-10-28 Add revision 1.2.1
    [Apalis-Smart-Vision-Baseboard-Rev.1.2.1.PrjPcb, Camera-Interface.SchDoc, Debug-UART.SchDoc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]
2020-10-28 Add documentation for release 1.2.1
    [Apalis-Smart-Vision-Baseboard-Rev.1.2.1-bom.csv, Apalis-Smart-Vision-Baseboard-Rev.1.2.1-pnp.csv]
